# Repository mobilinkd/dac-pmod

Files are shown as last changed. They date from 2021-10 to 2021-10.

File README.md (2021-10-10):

# DAC PMOD

This is a 4-channel sigma-delta DAC PMOD.  This provides an RC-filtered
and op-amp buffered output for a sigma delta modulator.

The resistor and capacitor values are not specified.  The expectation
is that users will have their own requirements for the filter cut-off.

When calculating the component values for the cut-off frequency of the
RC filter, bear in mind that a 200 ohm series resistor exists on each
PMOD signal line.

This repo contains KiCAD files and Gerbers for those wanting to make their
own boards.

This project is OSHW (Open Source Hardware), released under the GPLv3 license.

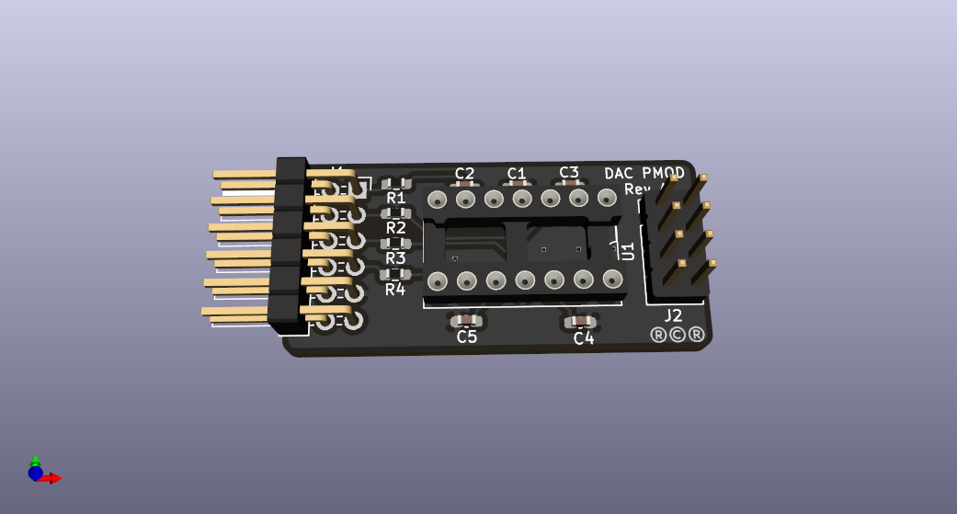
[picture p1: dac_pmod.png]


If you are interested in purchasing kits or complete modules, please contant
me at rob@mobilinkd.com.

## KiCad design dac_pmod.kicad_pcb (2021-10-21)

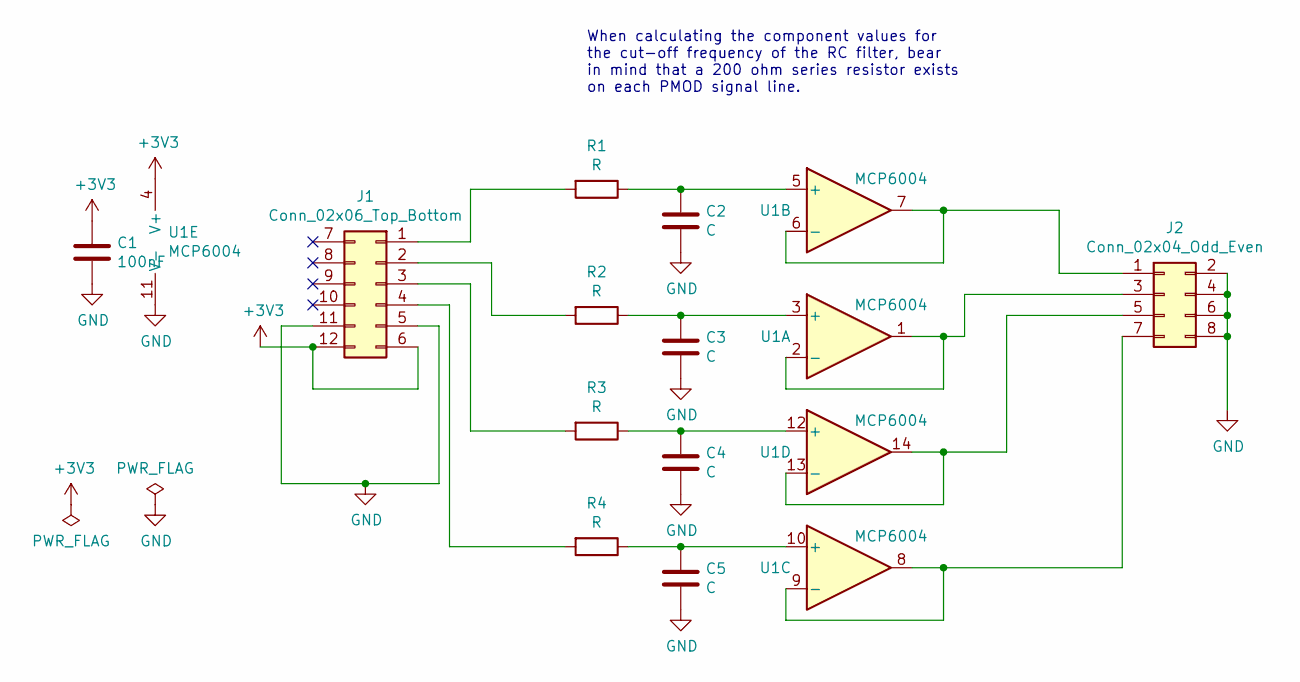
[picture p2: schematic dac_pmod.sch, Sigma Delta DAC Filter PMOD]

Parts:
C1: 100nF; C_0603_1608Metric_Pad1.08x0.95mm_HandSolder
C2, C3, C4, C5: C; C_0603_1608Metric_Pad1.08x0.95mm_HandSolder
J1: Conn_02x06_Top_Bottom; PinHeader_2x06_P2.54mm_Horizontal
J2: Conn_02x04_Odd_Even; PinHeader_2x04_P2.54mm_Vertical
R1, R2, R3, R4: R; R_0603_1608Metric_Pad0.98x0.95mm_HandSolder
U1: MCP6004; DIP-14_W7.62mm_Socket

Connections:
+3V3: C1.1, J1.6, J1.12, U1.4 (V+)
GND: C1.2, C2.2, C3.2, C4.2, C5.2, J1.5, J1.11, J2.2, J2.4, J2.6, J2.8, U1.11 (V-)
unnamed: C2.1, R1.1, U1.5 (+)
unnamed: C3.1, R2.1, U1.3 (+)
unnamed: C4.1, R3.1, U1.12 (+)
unnamed: C5.1, R4.1, U1.10 (+)
unnamed: J1.1, R1.2
unnamed: J1.2, R2.2
unnamed: J1.3, R3.2
unnamed: J1.4, R4.2
unnamed: J2.1, U1.6 (-), U1.7
unnamed: J2.3, U1.1, U1.2 (-)
unnamed: J2.5, U1.13 (-), U1.14
unnamed: J2.7, U1.8, U1.9 (-)

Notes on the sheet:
When calculating the component values for the cut-off frequency of the RC filter, bear in mind that a 200 ohm series resistor exists on each PMOD signal line.

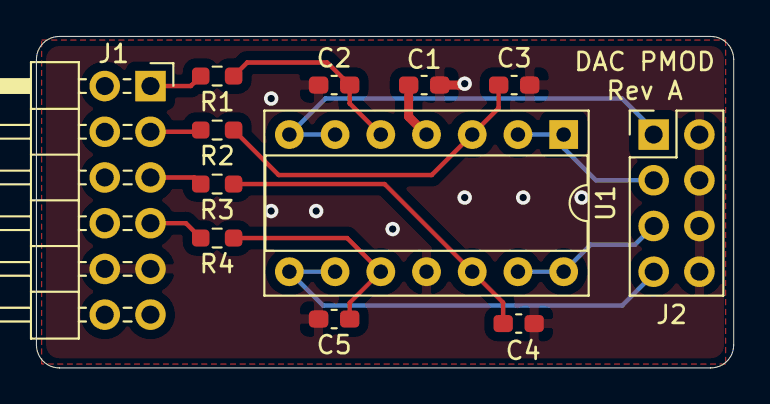
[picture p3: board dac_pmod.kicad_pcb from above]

Board: 4 copper layers, 38.7 x 18.4 mm, 13 parts (1 on the bottom side), 14 nets.

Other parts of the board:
G1: LOGO; Mobilinkd_Logo

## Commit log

2021-10-10 Initial commit.
    [dac_pmod-B_Cu.gbr, dac_pmod-B_Mask.gbr, dac_pmod-B_SilkS.gbr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]
2021-10-21 Update to 4-layer design because... why not.
    [dac_pmod-B_Mask.gbr, dac_pmod-B_SilkS.gbr, dac_pmod-Edge_Cuts.gbr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]
